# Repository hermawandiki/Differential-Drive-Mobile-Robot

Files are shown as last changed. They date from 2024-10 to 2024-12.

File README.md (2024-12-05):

# Differential-Drive-Mobile-Robot

This DDMR is equipped with a GUI that is able to display sensor data from the robot, control the movement of the robot, and set PID parameters for the speed of each motor.

This project was developed in the mechatronics system programming course at Mechatronics Engineering - EEPIS

Course lecturer : Adytia Darmawan, S.ST., M.T.

Mechatronics Engineering Study Program

Electronic Engineering Polytechnic Institute of Surabaya (EEPIS)

#

DDMR ini dilengkapi dengan GUI yang mampu menampilkan data sensor dari robot, mengendalikan pergerakan robot, dan mengatur parameter PID untuk kecepatan setiap motor.

Proyek ini dikembangkan dalam mata kuliah pemrograman sistem mekatronika di Teknik Mekatronika - PENS

Dosen Mata Kuliah : Adytia Darmawan, S.ST., M.T.

Program Studi Teknik Mekatronika

Politeknik Elektronika Negeri Surabaya (PENS)

#

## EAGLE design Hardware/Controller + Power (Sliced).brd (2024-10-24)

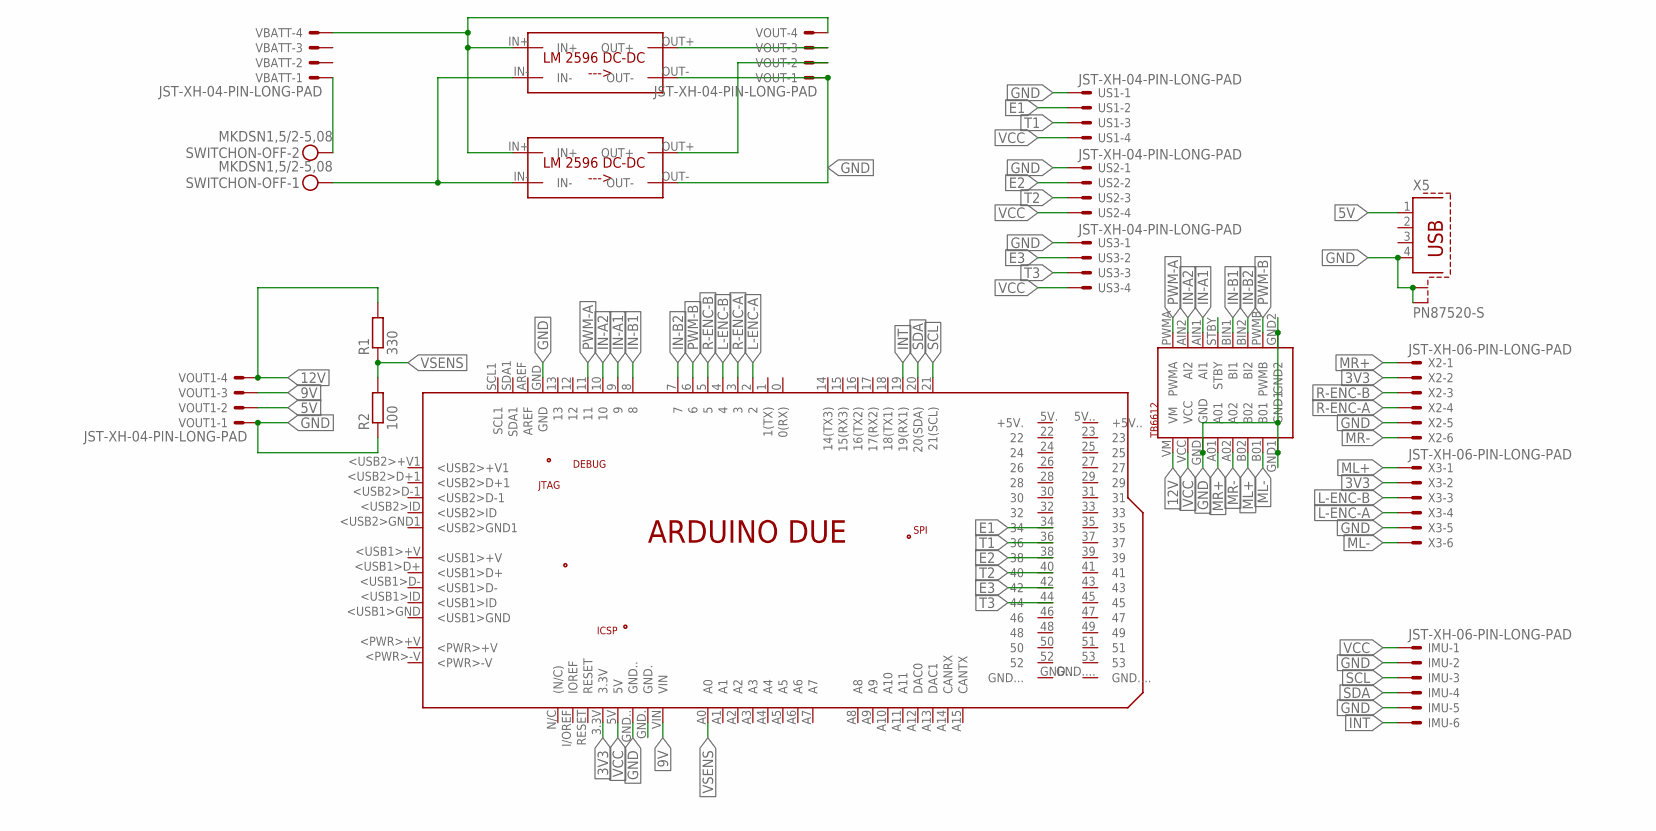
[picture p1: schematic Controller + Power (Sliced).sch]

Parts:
IMU: JST-XH-06-PIN-LONG-PAD; JST-XH-06-PACKAGE-LONG-PAD
PCB1: ARDUINO_DUE
R1: 330; R1206
R2: 100; R1206
SWITCHON-OFF: MKDSN1,5/2-5,08
U$1, U$2: LM2596_MODBUCK; LM2596_MOD
U$3: TB6612
US1, US2, US3: JST-XH-04-PIN-LONG-PAD; JST-XH-04-PACKAGE-LONG-PAD
VBATT: JST-XH-04-PIN-LONG-PAD; JST-XH-04-PACKAGE-LONG-PAD
VOUT, VOUT1: JST-XH-04-PIN-LONG-PAD; JST-XH-04-PACKAGE-LONG-PAD
X2, X3: JST-XH-06-PIN-LONG-PAD; JST-XH-06-PACKAGE-LONG-PAD
X5: PN87520-S

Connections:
3V3: PCB1.3.3V, X2.2, X3.2
5V: VOUT1.2, X5.1
9V: PCB1.VIN, VOUT1.3
12V: R1.2, U$3.VM, VOUT1.4
E1: PCB1.34, US1.2
E2: PCB1.38, US2.2
E3: PCB1.42, US3.2
GND: IMU.2, IMU.5, PCB1.GND, PCB1.GND.., R2.1, U$1.OUT-, U$2.OUT-, U$3.GND, U$3.GND1, U$3.GND2, US1.1, US2.1, US3.1, VOUT.1, VOUT1.1, X2.5, X3.5, X5.4, X5.S1, X5.S2
IN-A1: PCB1.9, U$3.AIN1 (AI1)
IN-A2: PCB1.10, U$3.AIN2 (AI2)
IN-B1: PCB1.8, U$3.BIN1 (BI1)
IN-B2: PCB1.7, U$3.BIN2 (BI2)
INT: IMU.6, PCB1.19 (19(RX1))
L-ENC-A: PCB1.2, X3.4
L-ENC-B: PCB1.4, X3.3
ML+: U$3.B02, X3.1
ML-: U$3.B01, X3.6
MR+: U$3.A01, X2.1
MR-: U$3.A02, X2.6
unnamed: U$1.IN+, U$2.IN+, VBATT.4, VOUT.4
unnamed: SWITCHON-OFF.2, VBATT.1
unnamed: SWITCHON-OFF.1, U$1.IN-, U$2.IN-
unnamed: U$2.OUT+, VOUT.3
unnamed: U$1.OUT+, VOUT.2
PWM-A: PCB1.11, U$3.PWMA
PWM-B: PCB1.6, U$3.PWMB
R-ENC-A: PCB1.3, X2.4
R-ENC-B: PCB1.5, X2.3
SCL: IMU.3, PCB1.21 (21(SCL))
SDA: IMU.4, PCB1.20 (20(SDA))
T1: PCB1.36, US1.3
T2: PCB1.40, US2.3
T3: PCB1.44, US3.3
VCC: IMU.1, PCB1.5V, U$3.VCC, US1.4, US2.4, US3.4
VSENS: PCB1.A0, R1.1, R2.2

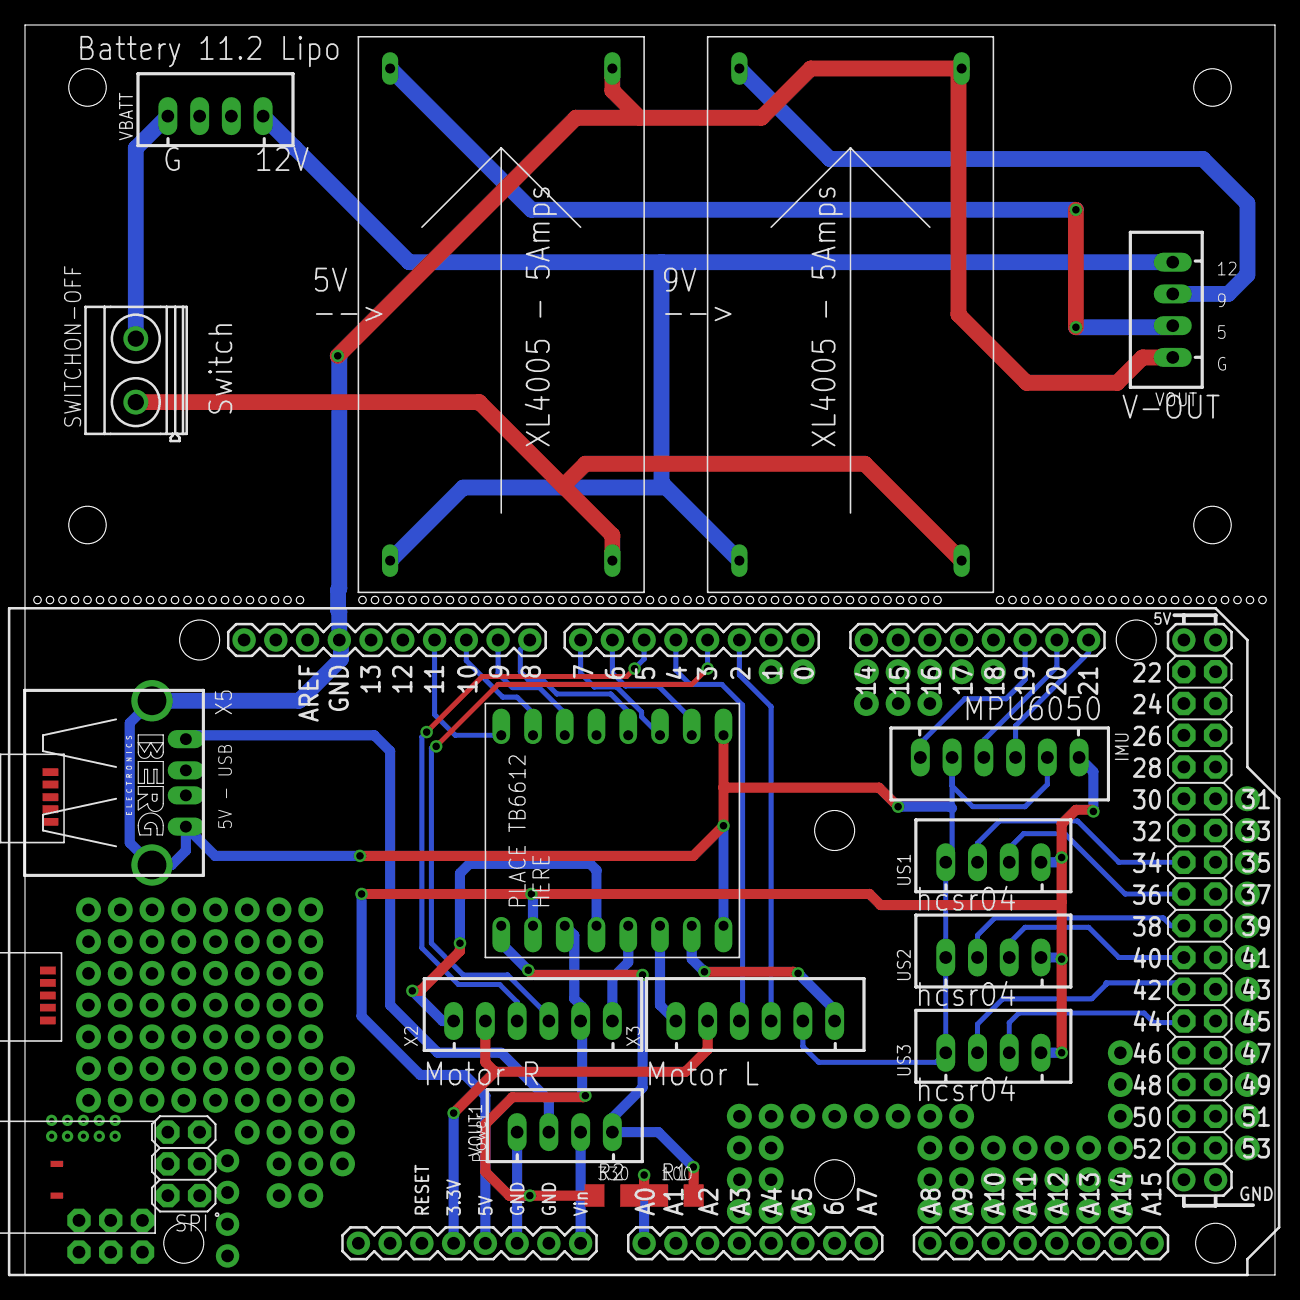
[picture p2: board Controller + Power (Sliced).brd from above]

Board: 2 copper layers, 100.0 x 100.0 mm, 17 parts (0 on the bottom side), 35 nets.

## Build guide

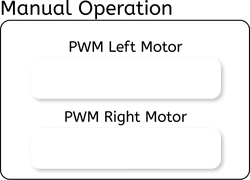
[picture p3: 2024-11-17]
GUI/build/assets/frame0/image_3.png

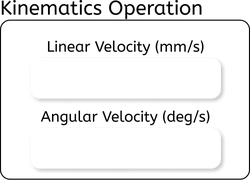
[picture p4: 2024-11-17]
GUI/build/assets/frame0/image_4.png

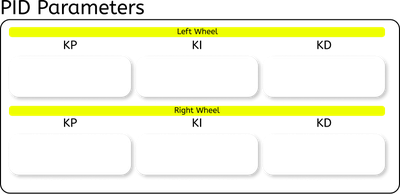
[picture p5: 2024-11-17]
GUI/build/assets/frame0/image_1.png

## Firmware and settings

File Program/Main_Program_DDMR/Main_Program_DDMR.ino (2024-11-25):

#include <EEPROM.h>
#include <Arduino_FreeRTOS.h>
#include <ArduinoJson.h>
#include <util/atomic.h>
#include <Ultrasonic.h>
#include "Wire.h"
#include "MPU6050_6Axis_MotionApps20.h"

// MOTOR
#define PWM_R 11
#define IN1_R 10
#define IN2_R 9
#define IN1_L 8
#define IN2_L 7
#define PWM_L 6

// ENCODER
#define ENCA_L 2
#define ENCB_L 4
#define ENCA_R 3
#define ENCB_R 5

// SENSOR
#define TRIG_LEFT   36
#define ECHO_LEFT   34
#define TRIG_RIGHT  44
#define ECHO_RIGHT  42
#define TRIG_FRONT  40
#define ECHO_FRONT  38
#define INTERRUPT_PIN   23

// WHEEL CONFIGURATION
#define WHEEL_DIAMETER 0.068 // in meters
#define WHEEL_RADIUS (WHEEL_DIAMETER / 2.0)
#define WHEELBASE 0.18 // in meters

// STATE MODE
#define TEST_MOTOR      1
#define WALL_FOLLOWING  2
#define AUTONOMOUS      3
#define TELEOPERATION   4
#define KANAN           1
#define KIRI            2

// ULTRASONIC
Ultrasonic US_Left (TRIG_LEFT,  ECHO_LEFT);
Ultrasonic US_Right(TRIG_RIGHT, ECHO_RIGHT);
Ultrasonic US_Front(TRIG_FRONT, ECHO_FRONT);

// IMU
MPU6050 mpu;
bool dmpReady = false;
uint8_t mpuIntStatus;
uint8_t devStatus;
uint16_t packetSize;
uint16_t fifoCount;
uint8_t fifoBuffer[64];
Quaternion q;
VectorFloat gravity;
float euler[3];
float ypr[3];
int Yaw, Pitch, Roll;
volatile bool mpuInterrupt = false;
void dmpDataReady() {
  mpuInterrupt = true;
}

char buffer[50];
uint8_t state = 0;
bool isRun = false;

volatile int encoderL, encoderR;
int posReadL, posReadR;
int prevPosReadL, prevPosReadR;
int deltaPosL, deltaPosR;
float speedActualL, speedActualR;
float speedSetpointL, speedSetpointR;

float errorL, prevErrorL;
float integralL, derivativeL;
float controlL, velocityL;
float KpL = 10;
float KiL = 0;
float KdL = 0;
float errorR, prevErrorR;
float integralR, derivativeR;
float controlR, velocityR;
float KpR = 10;
float KiR = 0;
float KdR = 0;

int us_kiri, us_depan, us_kanan;
int pwm1, pwm2;
float _vy, _omega;

float dt = 0.08;  // 80ms
int dtDelay = dt * 1000;
float vy, omega;

uint8_t balance;

void TaskMotorControl (void *pvParameters);
void TaskMainProgram  (void *pvParameters);
void TaskKirimSerial  (void *pvParameters);

void setup() {
  Serial.begin(115200);
  Wire.begin();
  Wire.setClock(400000);
  pinMode(PWM_L, OUTPUT);
  pinMode(PWM_R, OUTPUT);
  pinMode(IN1_L, OUTPUT);
  pinMode(IN2_L, OUTPUT);
  pinMode(IN1_R, OUTPUT);
  pinMode(IN2_R, OUTPUT);
  pinMode(ENCA_L, INPUT_PULLUP);
  pinMode(ENCB_L, INPUT_PULLUP);
  pinMode(ENCA_R, INPUT_PULLUP);
  pinMode(ENCB_R, INPUT_PULLUP);

  attachInterrupt(digitalPinToInterrupt(ENCA_L), HandleENC_L, RISING);
  attachInterrupt(digitalPinToInterrupt(ENCA_R), HandleENC_R, RISING);
  
  initMPU();
  readEEPROM();

  xTaskCreate(TaskMotorControl, "Kinematika & PID", 1024, NULL, 1, NULL);
  xTaskCreate(TaskMainProgram, "Main Program", 1024, NULL, 1, NULL);
  xTaskCreate(TaskKirimSerial, "Kirim Data GUI", 1024, NULL, 1, NULL);
}

void loop() {
  // null
}
//
void initMPU() {
  mpu.initialize();
  devStatus = mpu.dmpInitialize();
  mpu.setXGyroOffset(220);
  mpu.setYGyroOffset(76);
  mpu.setZGyroOffset(-85);
  mpu.setZAccelOffset(1788);

  if (devStatus == 0) {
    mpu.CalibrateAccel(6);
    mpu.CalibrateGyro(6);
    mpu.PrintActiveOffsets();
    mpu.setDMPEnabled(true);
    attachInterrupt(digitalPinToInterrupt(INTERRUPT_PIN), dmpDataReady, RISING);
    mpuIntStatus = mpu.getIntStatus();
    dmpReady = true;
    packetSize = mpu.dmpGetFIFOPacketSize();
  } else {}
}
//
void HandleENC_L() {
  digitalRead(ENCB_L) ? encoderL++ : encoderL--;
}
//
void HandleENC_R() {
  digitalRead(ENCB_R) ? encoderR++ : encoderR--;
}
//
void driveMotor(int pwm1, int pwm2) {
  if (pwm1 > 0) {
    digitalWrite(IN1_L, LOW);
    digitalWrite(IN2_L, HIGH);
  } else {
    digitalWrite(IN1_L, HIGH);
    digitalWrite(IN2_L, LOW);
  }

  if (pwm2 > 0) {
    digitalWrite(IN1_R, LOW);
    digitalWrite(IN2_R, HIGH);
  } else {
    digitalWrite(IN1_R, HIGH);
    digitalWrite(IN2_R, LOW);
  }

  pwm1 = constrain(abs(pwm1), 0, 255);
  pwm2 = constrain(abs(pwm2), 0, 255);

  analogWrite(PWM_L, pwm1);
  analogWrite(PWM_R, pwm2);
}
//
void kinematic(float vy, float omega) {
  // Konversi vy (mm/s) menjadi m/s
  vy = vy / 1000.0;
  // Konversi w (deg/s) menjadi rad/s
  omega = omega * M_PI / 180.0;

  // Hitung kecepatan roda kiri (v_l) dan roda kanan (v_r) dalam m/s
  float vl = vy + (WHEELBASE / 2.0) * omega;
  float vr = vy - (WHEELBASE / 2.0) * omega;

  // Konversi dari m/s ke rps
  float rpsl = vl / (2.0 * M_PI * WHEEL_RADIUS);
  float rpsr = vr / (2.0 * M_PI * WHEEL_RADIUS);

  // Kirim ke PID
  int pwmL = PID_L(rpsl);
  int pwmR = PID_R(-rpsr);
  driveMotor(pwmL, pwmR);
}
//
int PID_L(float setpoint) {
  int out;
  // PID
  errorL = setpoint - speedActualL;
  integralL += errorL * dt;
  derivativeL = (errorL - prevErrorL) / dt;
  controlL = (KpL * errorL) + (KiL * integralL) + (KdL * derivativeL);
  // PWM
  velocityL = velocityL + controlL;
  out = constrain(velocityL, -255, 255);
  prevErrorL = errorL;

  return out;
}
//
int PID_R(float setpoint) {
  int out;
  // PID
  errorR = setpoint - speedActualR;
  integralR += errorR * dt;
  derivativeR = (errorR - prevErrorR) / dt;
  controlR = (KpR * errorR) + (KiR * integralR) + (KdR * derivativeR);
  // PWM
  velocityR = velocityR + controlR;
  out = constrain(velocityR, -255, 255);
  prevErrorR = errorR;

  return out;
}
//
void kirimDataJson() {
  StaticJsonDocument<256> doc;

  doc["usl"]    = us_kiri;
  doc["usf"]    = us_depan;
  doc["usr"]    = us_kanan;
  doc["yaw"]    = Yaw;
  doc["pitch"]  = Pitch;
  doc["roll"]   = Roll;
  doc["encl"]   = encoderL;
  doc["encr"]   = encoderR;
  doc["kpl"]    = KpL;
  doc["kil"]    = KiL;
  doc["kdl"]    = KdL;
  doc["kpr"]    = KpR;
  doc["kir"]    = KiR;
  doc["kdr"]    = KdR;

  char jsonBuffer[256];
  serializeJson(doc, jsonBuffer);
  Serial.println(jsonBuffer);

  //    sprintf(buffer, "#U%dU%dU%dE%dE%d", us_kiri, us_depan, us_kanan, encoderL, encoderR);
  //    Serial.print(buffer);
  //    String dataF = 'Y' + String(yaw,2) + 'P'+ String(pitch,2) + 'R' + String(roll,2) + 'X' + String(pos_x,2) + 'Y' + String(pos_y,2) + 'W' + String(pos_w,2);
  //    Serial.println(dataF);
}
//
void writeEEPROM() {
  int addr = 0;

  EEPROM.put(addr, KpL); addr += sizeof(KpL);
  EEPROM.put(addr, KpR); addr += sizeof(KpR);
  EEPROM.put(addr, KiL); addr += sizeof(KiL);
  EEPROM.put(addr, KiR); addr += sizeof(KiR);
  EEPROM.put(addr, KdL); addr += sizeof(KdL);
  EEPROM.put(addr, KdR); addr += sizeof(KdR);
}
//
void readEEPROM() {
  int addr = 0;

  EEPROM.get(addr, KpL); addr += sizeof(KpL);
  EEPROM.get(addr, KpR); addr += sizeof(KpR);
  EEPROM.get(addr, KiL); addr += sizeof(KiL);
  EEPROM.get(addr, KiR); addr += sizeof(KiR);
  EEPROM.get(addr, KdL); addr += sizeof(KdL);
  EEPROM.get(addr, KdR); addr += sizeof(KdR);
}
//
void TaskMotorControl(void *pvParameters) {
  for (;;) {
    noInterrupts();
    posReadL = encoderL;
    posReadR = encoderR;
    if (state != TEST_MOTOR) kinematic(vy, omega);
    else driveMotor(pwm1, pwm2);
    interrupts();
    deltaPosL = posReadL - prevPosReadL;
    deltaPosR = posReadR - prevPosReadR;
    prevPosReadL = posReadL;
    prevPosReadR = posReadR;
    speedActualL = deltaPosL / dt / 320;
    speedActualR = deltaPosR / dt / 320;
    if (state != TEST_MOTOR) kinematic(vy, omega);
    else driveMotor(pwm1, pwm2);
    vTaskDelay(dtDelay / portTICK_PERIOD_MS);
  }
}
//
void TaskMainProgram(void *pvParameters) {
  int _pwm1, _pwm2;
  float _vy, _omega;
  for (;;) {
    if (Serial.available() > 0) {
      char data = Serial.read();
      switch (data) {
        case 'T' : state = TELEOPERATION;   isRun = false;  break;
        case 'P' : state = TEST_MOTOR;      isRun = false;  break;
        case 'A' : state = AUTONOMOUS;      isRun = false;  break;
        case 'W' : state = WALL_FOLLOWING;  isRun = false;  break;
        case 'M' : isRun = true;                            break;
        case 'N' : isRun = false;                           break;
        case 'I' : _vy = Serial.parseFloat();               break;
        case 'K' : _vy = -(Serial.parseFloat());            break;
        case 'J' : _omega = -(Serial.parseFloat());         break;
        case 'L' : _omega = Serial.parseFloat();            break;
        case 'X' : _vy = 0; _omega = 0;                     break;
        case 'Q' : {
            _pwm1 = Serial.parseInt();
            _pwm2 = Serial.parseInt();
          }
          break;
        case '#' : {
            KpL = Serial.parseFloat();
            KpR = Serial.parseFloat();
            KiL = Serial.parseFloat();
            KiR = Serial.parseFloat();
            KdL = Serial.parseFloat();
            KdR = Serial.parseFloat();

            writeEEPROM();
          }
          break;
        default: break;
      }
    }

    switch (state) {
      case TEST_MOTOR :
        if (isRun) {
          pwm1 = _pwm1;
          pwm2 = _pwm2;
        }
        else {
          pwm1 = 0;
          pwm2 = 0;
        }
        break;
      case TELEOPERATION :
        robotVelocity(_vy, _omega);
        break;
      case AUTONOMOUS :
        runAutonomous();
        break;
      case WALL_FOLLOWING :
        wallFollowing();
        break;
      default :
        break;
    }

    //    Serial.print(state);
    //    Serial.print(" ");
    //    Serial.println(isRun);

    vTaskDelay(dtDelay / portTICK_PERIOD_MS);
  }
}
//
void TaskKirimSerial(void *pvParameters) {
  for (;;) {
    if (!dmpReady) return;
    if (mpu.dmpGetCurrentFIFOPacket(fifoBuffer)) {
      mpu.dmpGetQuaternion(&q, fifoBuffer);
      mpu.dmpGetGravity(&gravity, &q);
      mpu.dmpGetYawPitchRoll(ypr, &q, &gravity);

      Pitch = ypr[2] * 180 / M_PI;
      Roll  = ypr[1] * 180 / M_PI;
      Yaw   = ypr[0] * 180 / M_PI;
    }
    us_depan = US_Front.read();
    us_kiri  = US_Left.read();
    us_kanan = US_Right.read();

    kirimDataJson();

    vTaskDelay(10 / portTICK_PERIOD_MS);
  }
}
//
void robotVelocity(float y, float w) {
  vy    = y;
  omega = w;
}
//
void runAutonomous() {
  if (!isRun) robotVelocity(0, 0);
  else {
    if (us_depan > 20) robotVelocity(300, 0);
    else {
      robotVelocity(0, 90);
      delay(1000);
      robotVelocity(0, 0);
    }
  }
}
//
void wallFollowing() {

}
//

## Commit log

2024-10-24 move from local to github
    [Controller + Power (Sliced).brd, Controller + Power (Sliced).sch]
2024-12-04 update, sudah di-review
